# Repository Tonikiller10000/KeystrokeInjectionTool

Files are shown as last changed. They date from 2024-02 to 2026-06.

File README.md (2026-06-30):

# KeystrokeInjectionTool

## KeystrokeInjectionTool_V1.0
The first board was made at home in an arduino shield form put over an arduino uno. 
The projection was printed on the [heat tstransfer paper](https://github.com/Tonikiller10000/KeystrokeInjectionTool/blob/main/KeystrokeInjectionTool_V1.0/KeystrokeInjectionTool_Pictures/f.jpg) at the printer, after witch I put the [print on](https://github.com/Tonikiller10000/KeystrokeInjectionTool/blob/main/KeystrokeInjectionTool_V1.0/KeystrokeInjectionTool_Pictures/ff.jpg), by pressing the copper on a smd soldering plate. 
After the print is on the copper, the board was put in the feric clorhide and then cleaned. Then I drilled the holes of the [board](https://github.com/Tonikiller10000/KeystrokeInjectionTool/blob/main/KeystrokeInjectionTool_V1.0/KeystrokeInjectionTool_Pictures/fff.jpg), and [soldered](https://github.com/Tonikiller10000/KeystrokeInjectionTool/blob/main/KeystrokeInjectionTool_V1.0/KeystrokeInjectionTool_Pictures/c4.jpg) the smd and tht parts in this order. 
After [cleaning](https://github.com/Tonikiller10000/KeystrokeInjectionTool/blob/main/KeystrokeInjectionTool_V1.0/KeystrokeInjectionTool_Pictures/ffff.jpg), the board was [ready](https://github.com/Tonikiller10000/KeystrokeInjectionTool/blob/main/KeystrokeInjectionTool_V1.0/KeystrokeInjectionTool_Pictures/c22.jpg) for soldering. 

## The KeystrokeInjectionTool_V1.0 in action
This board was made from an arduino uno with this [homemade shield](https://github.com/Tonikiller10000/KeystrokeInjectionTool/blob/main/KeystrokeInjectionTool_V1.0/KeystrokeInjectionTool_Pictures/fffff.jpg) with buttons to activate the keystrokes comands.
The board worked pretty well, but sometimes, the keystrokes beginned faster and the program didn\`t run well. 
Here are 2 videos with the board being tested at home as a keyboard with keys and shortcuts 
[Vid1](https://github.com/Tonikiller10000/KeystrokeInjectionTool/blob/main/KeystrokeInjectionTool_V1.0/KeystrokeInjectionTool_Pictures/f1.mp4), 
[Vid2](https://github.com/Tonikiller10000/KeystrokeInjectionTool/blob/main/KeystrokeInjectionTool_V1.0/KeystrokeInjectionTool_Pictures/f2.mp4).

<table>
  <tr>
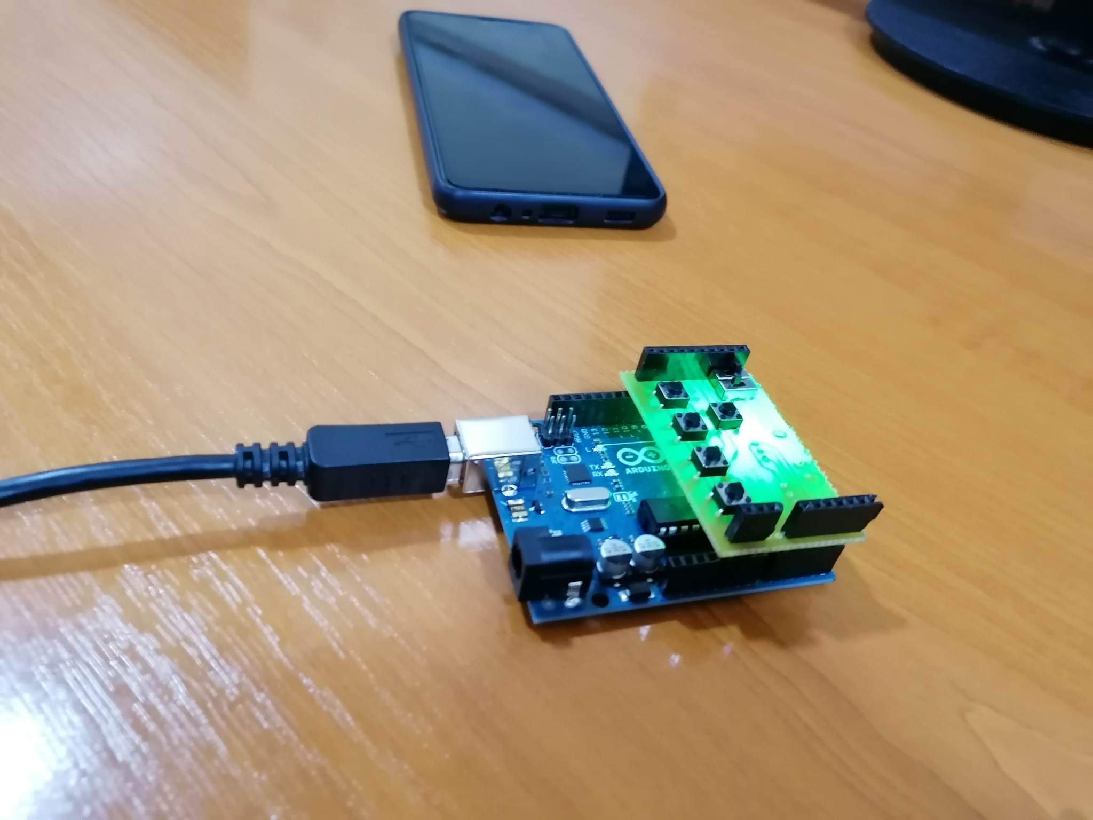
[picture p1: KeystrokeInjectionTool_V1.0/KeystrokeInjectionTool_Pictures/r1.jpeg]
    <td></td>
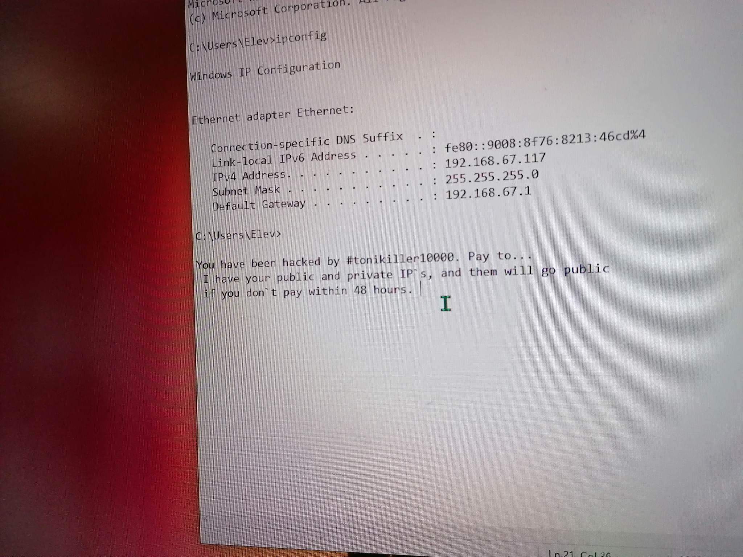
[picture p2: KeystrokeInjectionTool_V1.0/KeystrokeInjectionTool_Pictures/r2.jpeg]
    <td></td>
  </tr>
 </table>

## KeystrokeInjectionTool_V2.0
This board was designed like a normal USB Memory Stick. It has 2 dip switches and a [push button](https://github.com/Tonikiller10000/KeystrokeInjectionTool/blob/main/KeystrokeInjectionTool_V2.0/KeystrokeInjTool_Pictures/KS1.jpg) 
for user input, the ATTINY85 or ATTINY45 microcontroller, and an 256Kb I2C EEPROM for additional 256Kb of memmory. 
The stick case will have a sliding mechanism to have a steady grip instead of using holes. 
Now I have to wait the board to arrive and start working on it\`s case.

<table>
  <tr>
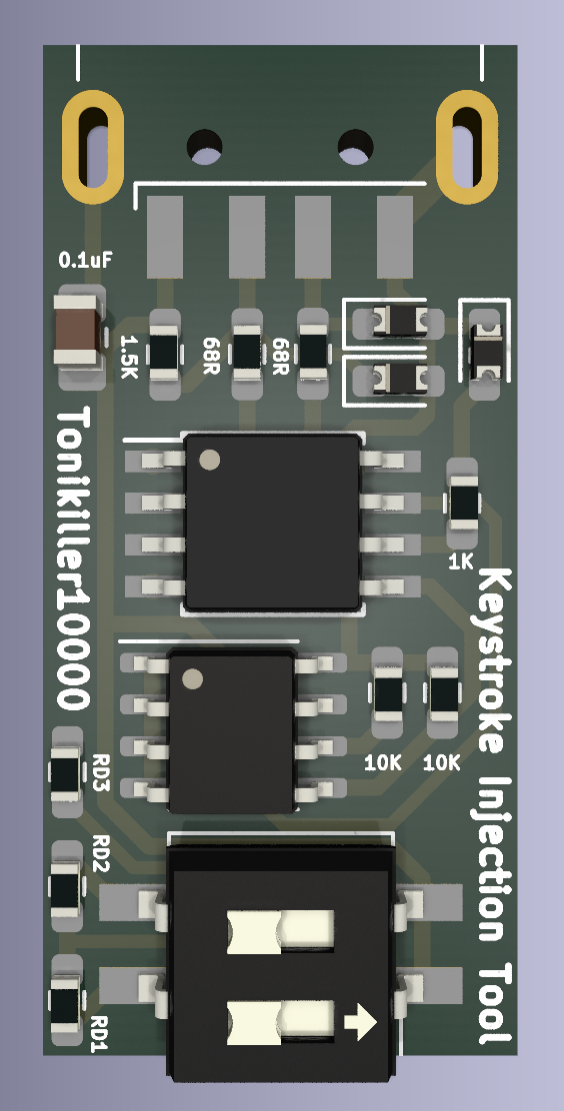
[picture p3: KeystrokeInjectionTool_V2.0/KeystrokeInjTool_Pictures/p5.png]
    <td></td>
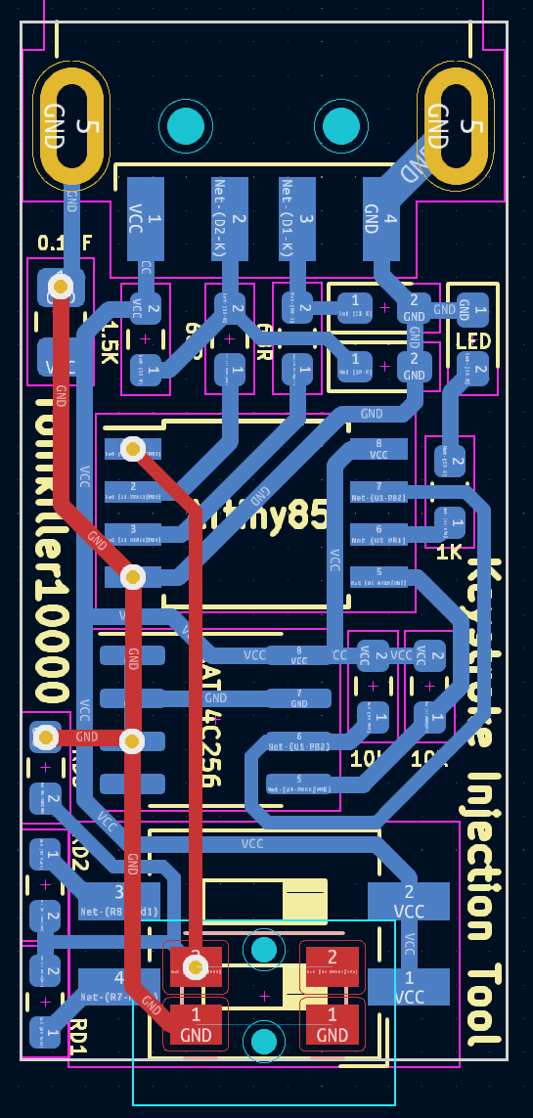
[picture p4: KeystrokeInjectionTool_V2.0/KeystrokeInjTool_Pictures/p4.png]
    <td></td>
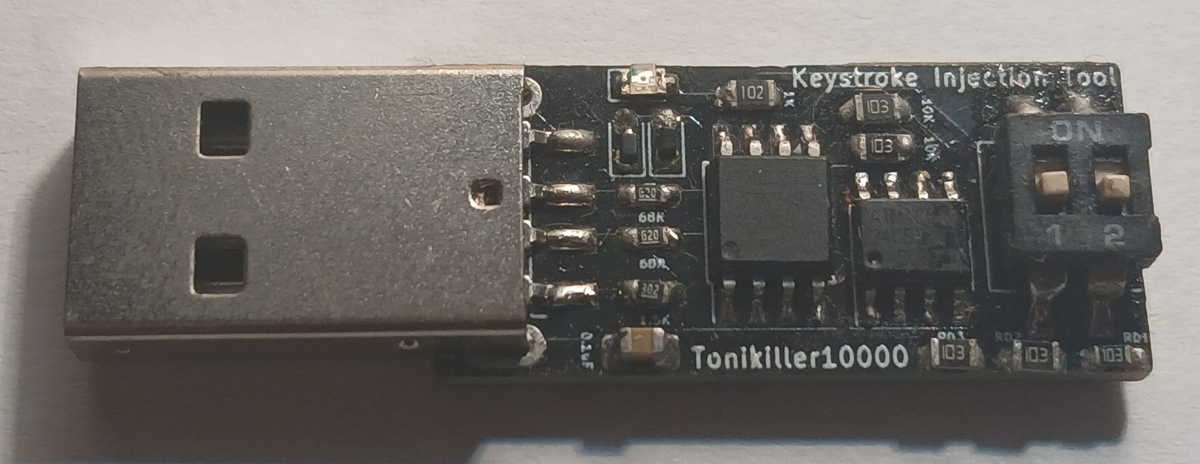
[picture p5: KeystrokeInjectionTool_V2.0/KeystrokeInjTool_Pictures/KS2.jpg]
    <td></td>
  </tr>
</table>

## Schematic:
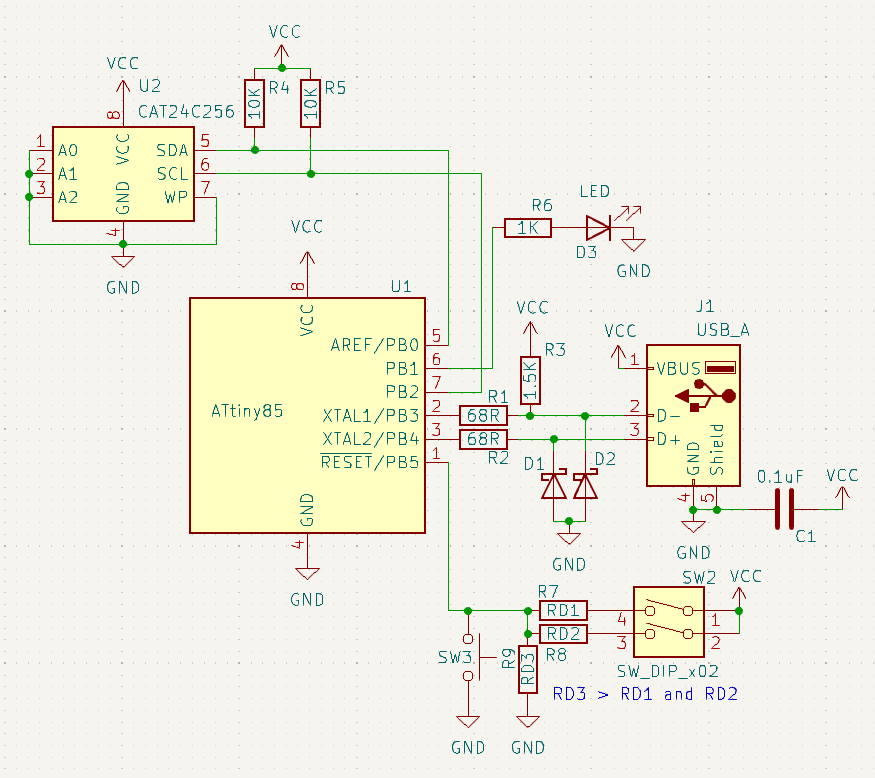
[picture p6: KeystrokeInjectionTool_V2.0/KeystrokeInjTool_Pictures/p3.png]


## Mentions:
- If I was to use an SD card instead of an I2C EEPROM, I wold\`ve needed 4 pins witch means I couldn\`t use the 4 switchees for code execution select. 
Maybe If someone want\`s to try with an aditional small IC to convert the SPI from the SD card to the I2C for the microcontroller. 
It would be in size like the current EEPROM and on the back of the device would be the SD socket.

- an upgrade would be using an stm32 as a keystroke injection tool.
The stm32 is capable of USB, SD card, buttons and leds at the same time and can do more advanced stuff hardware and software 
(you can also add a small i2c oled screen 32x128 to display witch code to execute. 
but that would require a small battery like a earbuud one or a coin one, or editing options after connection. 
with stm32 the keystoke injection tool can apear as a drive too and you can do something to copy the data on it.)

## Links:
- recomended video: https://youtu.be/XwEZvaGyKDE?si=0O5bhv-sC-1KsNow
- the basic schematic diagram: https://github.com/Tonikiller10000/KeystrokeInjectionTool/blob/main/KeystrokeInjectionTool_V2.0/KeystrokeInjTool_Pictures/p1.jpg
- CAT24C256(256Kb I2C EEPROM) datasheet: https://www.onsemi.com/pdf/datasheet/cat24c256-d.pdf

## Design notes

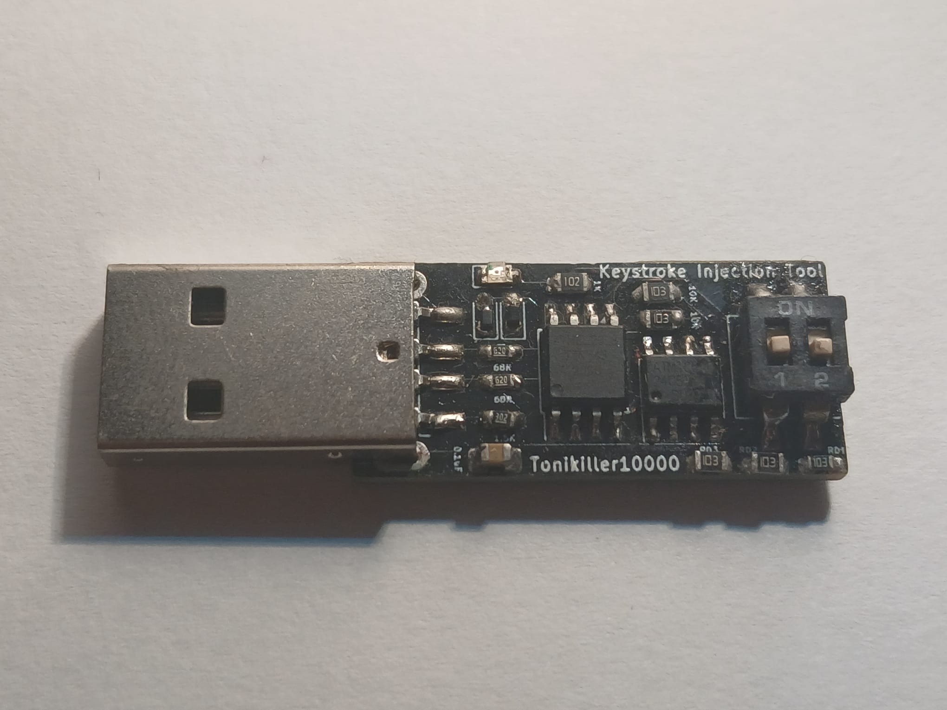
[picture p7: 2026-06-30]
KeystrokeInjectionTool_V2.0/KeystrokeInjTool_Pictures/keystroke (2).jpeg

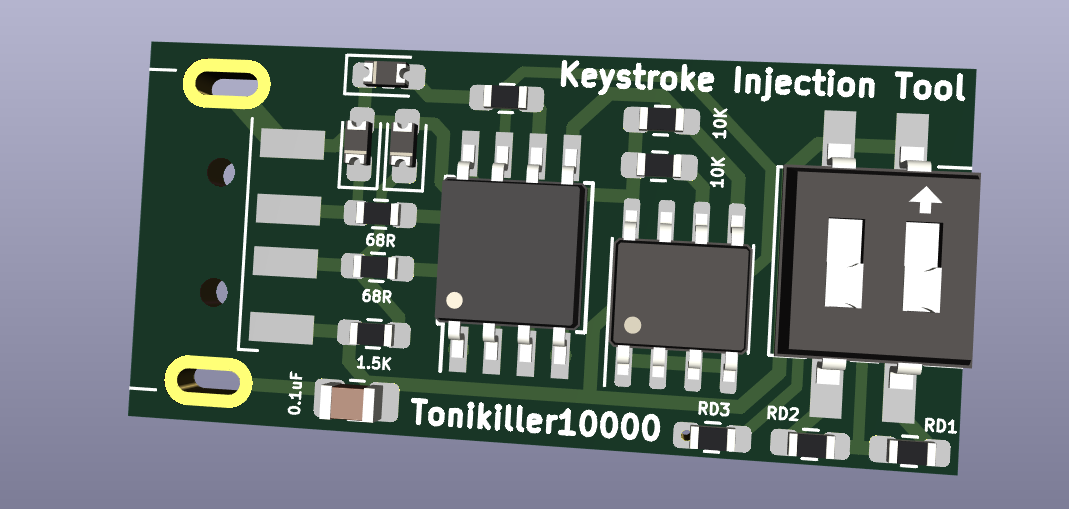
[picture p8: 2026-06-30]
KeystrokeInjectionTool_V2.0/KeystrokeInjTool_Pictures/Screenshot 2024-01-30 201149.png

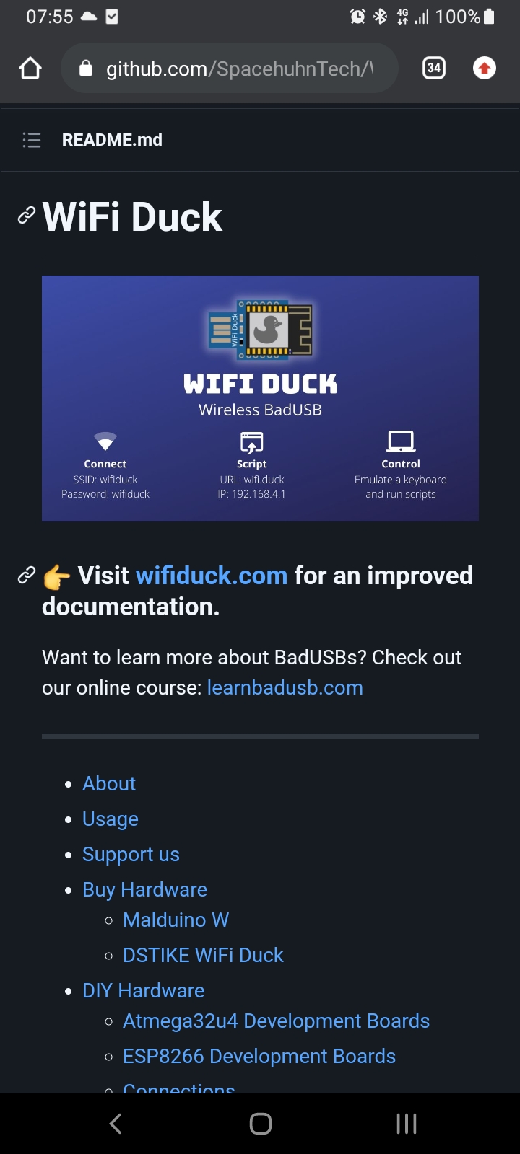
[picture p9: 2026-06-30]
KeystrokeInjectionTool_V2.0/KeystrokeInjTool_Pictures/Screenshot_20230331-075549_Chrome.jpg

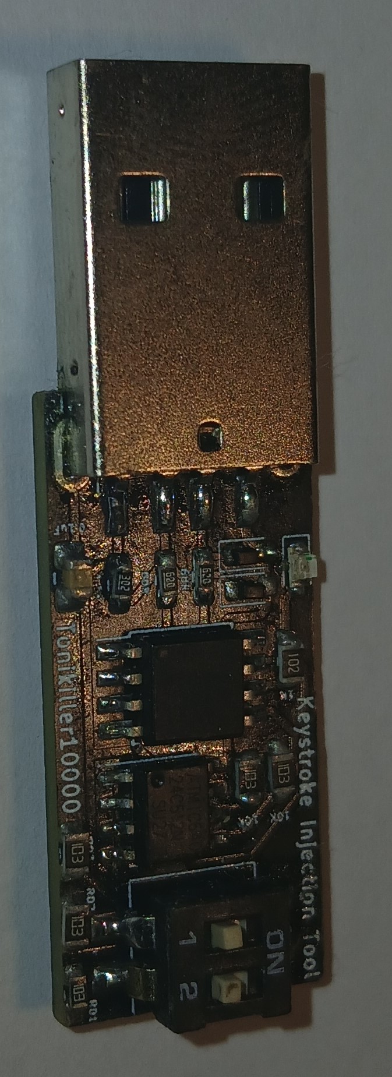
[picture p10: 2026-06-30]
KeystrokeInjectionTool_V2.0/KeystrokeInjTool_Pictures/KS3.jpg

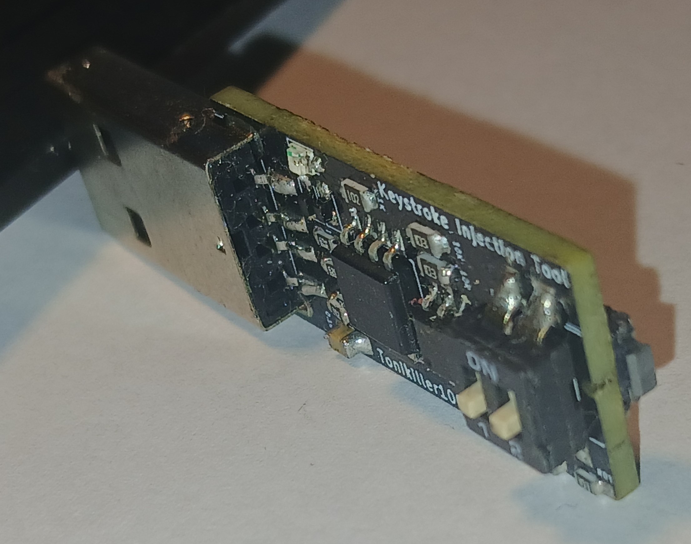
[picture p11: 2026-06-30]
KeystrokeInjectionTool_V2.0/KeystrokeInjTool_Pictures/KS1.jpg

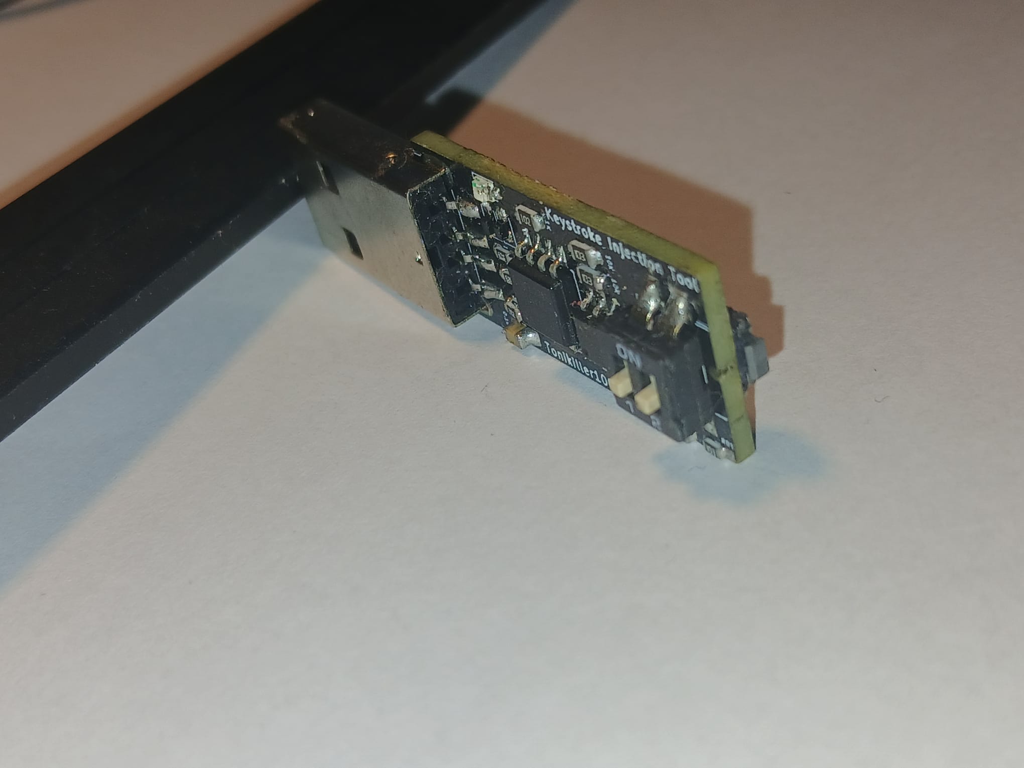
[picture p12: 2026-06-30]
KeystrokeInjectionTool_V2.0/KeystrokeInjTool_Pictures/keystroke (1).jpeg

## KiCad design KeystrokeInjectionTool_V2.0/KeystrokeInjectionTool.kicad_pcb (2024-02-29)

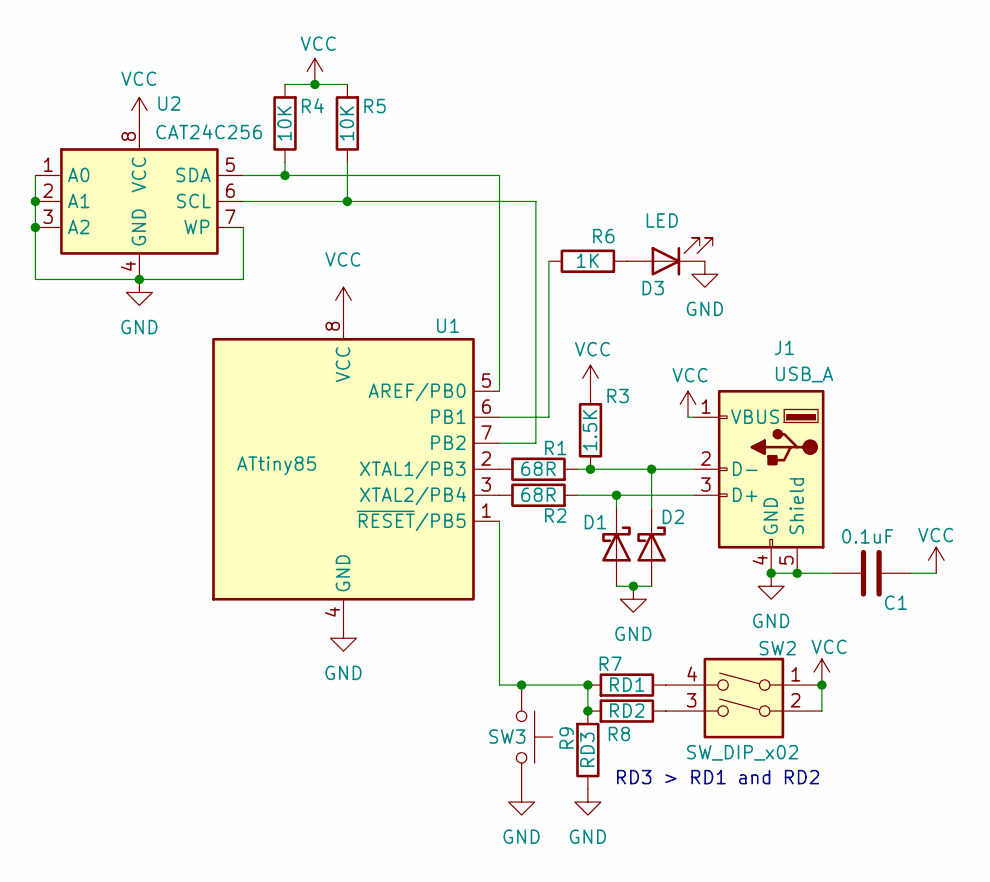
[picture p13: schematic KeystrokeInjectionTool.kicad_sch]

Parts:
C1: 0.1uF; C_0805_2012Metric_Pad1.18x1.45mm_HandSolder
D1, D2: 1N5711UR; D_0603_1608Metric_Pad1.05x0.95mm_HandSolder
D3: LED
J1: USB_A; USB_A_CNCTech_1001-011-01101_Horizontal
R1, R2: 68R; R_0603_1608Metric_Pad0.98x0.95mm_HandSolder
R3: 1.5K; R_0603_1608Metric_Pad0.98x0.95mm_HandSolder
R4, R5: 10K; R_0603_1608Metric_Pad0.98x0.95mm_HandSolder
R6: 1K; R_0603_1608Metric_Pad0.98x0.95mm_HandSolder
R7: RD1; R_0603_1608Metric_Pad0.98x0.95mm_HandSolder
R8: RD2; R_0603_1608Metric_Pad0.98x0.95mm_HandSolder
R9: RD3; R_0603_1608Metric_Pad0.98x0.95mm_HandSolder
SW2: SW_DIP_x02
SW3: SW_Push
U1: ATtiny85; SOIC-8W_5.3x5.3mm_P1.27mm
U2: CAT24C256; SOIC-8_3.9x4.9mm_P1.27mm

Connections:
GND: C1.1, D1.2 (A), D2.2 (A), D3.1 (K), J1.4 (GND), J1.5 (Shield), R9.1, SW3.1, U1.4 (GND), U2.1 (A0), U2.2 (A1), U2.3 (A2), U2.4 (GND), U2.7 (WP); also elsewhere on the board
unnamed: D1.1 (K), J1.3 (D+), R2.2
unnamed: D2.1 (K), J1.2 (D-), R1.2, R3.1
unnamed: D3.2 (A), R6.2
unnamed: R7.1, SW2.4
unnamed: R8.1, SW2.3
unnamed: R4.1, U1.5 (AREF/PB0), U2.5 (SDA)
unnamed: R6.1, U1.6 (PB1)
unnamed: R5.1, U1.7 (PB2), U2.6 (SCL)
unnamed: R1.1, U1.2 (XTAL1/PB3)
unnamed: R2.1, U1.3 (XTAL2/PB4)
unnamed 11: R7.2, R8.2, R9.2, SW3.2, U1.1 (~RESET/PB5); also elsewhere on the board
VCC: C1.2, J1.1 (VBUS), R3.2, R4.2, R5.2, SW2.1, SW2.2, U1.8 (VCC), U2.8 (VCC)

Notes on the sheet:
RD3 > RD1 and RD2

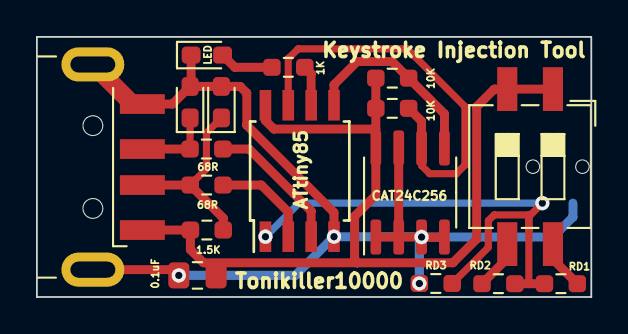
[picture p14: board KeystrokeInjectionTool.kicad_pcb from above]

Board: 2 copper layers, 30.8 x 14.5 mm, 18 parts (1 on the bottom side), 13 nets.

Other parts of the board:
SW1: SW_Push; Panasonic_EVQPUL_EVQPUC

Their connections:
GND: SW1.1; also elsewhere on the board
unnamed 11: SW1.2; also elsewhere on the board
